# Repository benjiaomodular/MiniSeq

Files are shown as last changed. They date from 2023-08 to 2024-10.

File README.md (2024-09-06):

# MiniSeq
[][cc-by-sa]

Full docs on my website: https://benjiaomodular.com/post/miniseq/

This is my second time building a Baby-8 step CV sequencer since my [plexiglass Baby-8 build](https://benjiaomodular.com/post/2021-04-09-8-step-sequencer) from two years ago. This, time I added a gate output, a reset input, and a step length control.

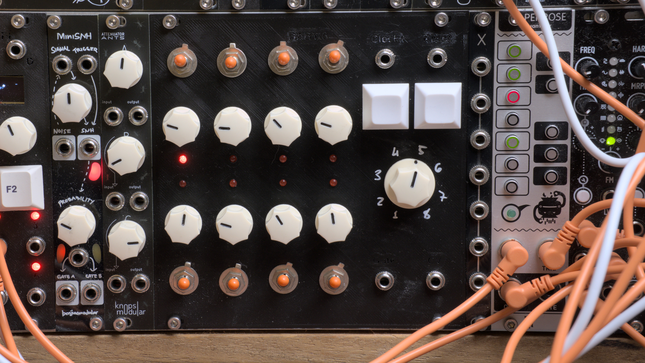
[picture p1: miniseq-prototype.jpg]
"My prototype for the MiniSeq build on a 3D printed panel"
 

## Schematics

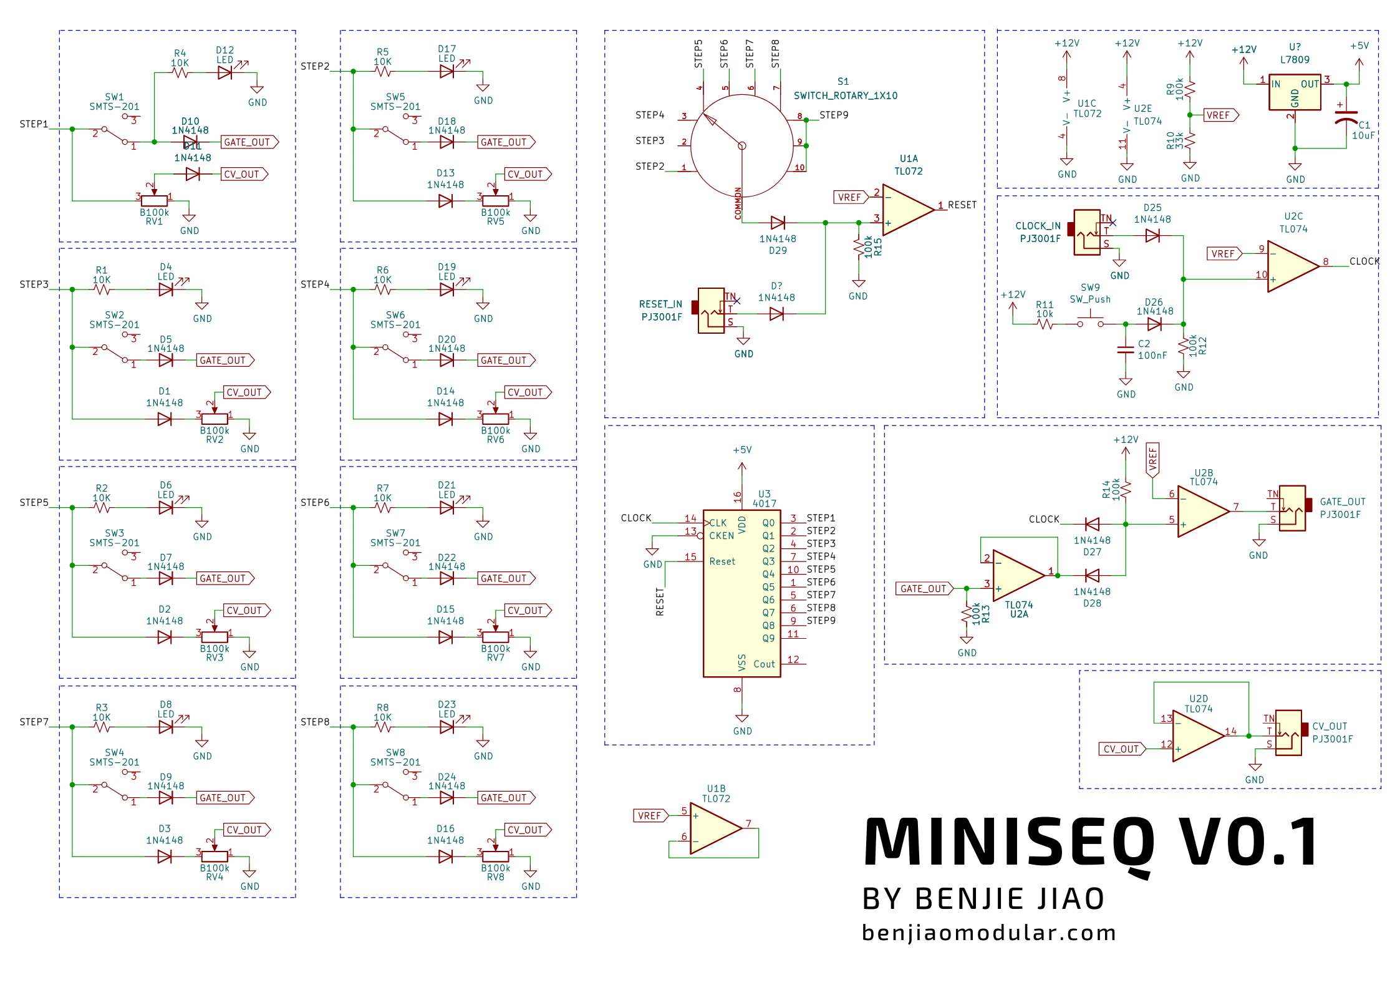
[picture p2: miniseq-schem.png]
"MiniSeq Schematics"
 

## License

This work is licensed under a
[Creative Commons Attribution-ShareAlike 4.0 International License][cc-by-sa].

[][cc-by-sa]

[cc-by-sa]: http://creativecommons.org/licenses/by-sa/4.0/
[cc-by-sa-image]: https://licensebuttons.net/l/by-sa/4.0/88x31.png
[cc-by-sa-shield]: https://img.shields.io/badge/License-CC%20BY--SA%204.0-lightgrey.svg

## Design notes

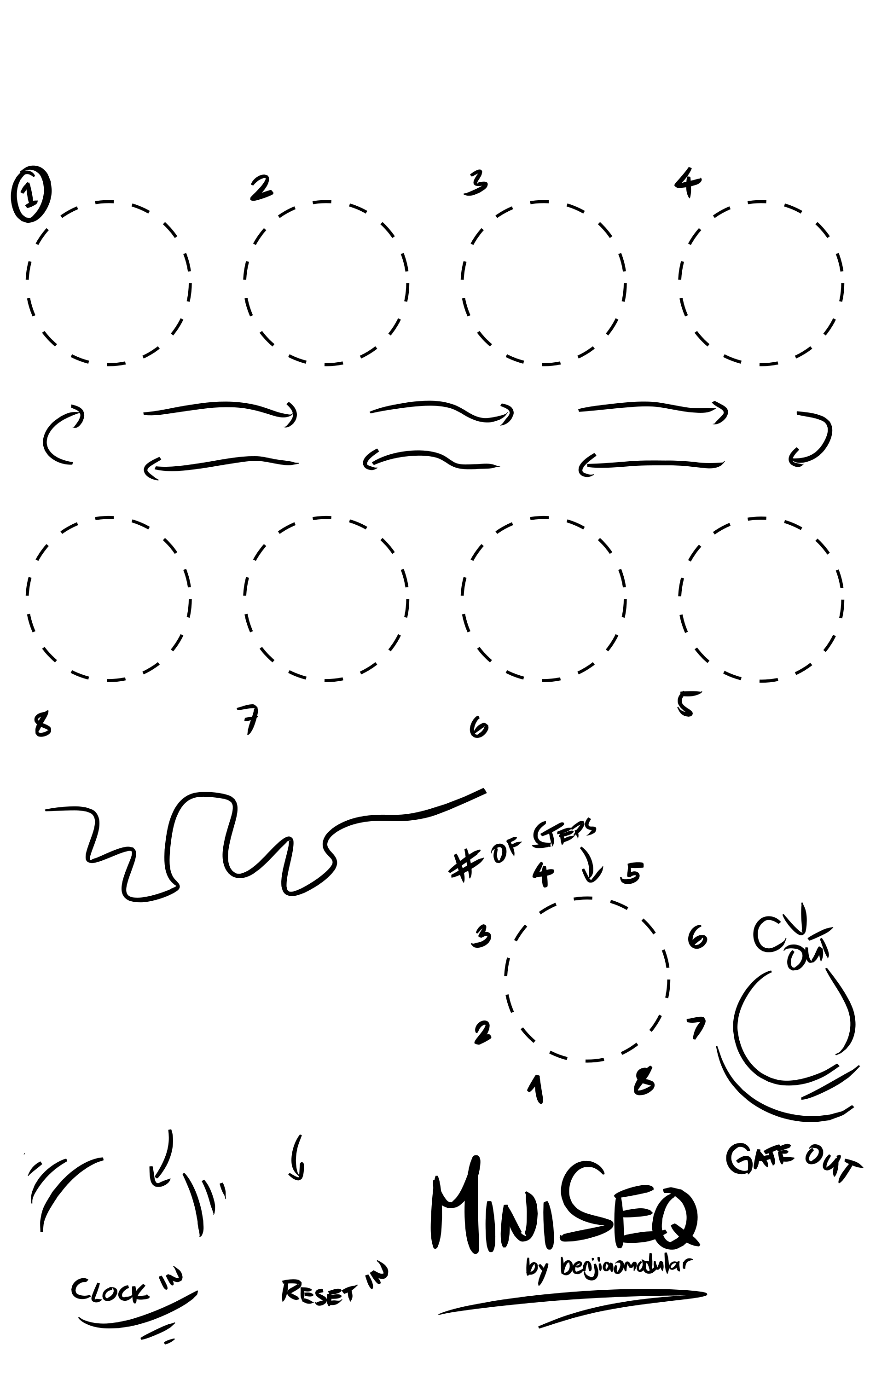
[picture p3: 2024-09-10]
hardware/panel/MiniSeq - Panel.png

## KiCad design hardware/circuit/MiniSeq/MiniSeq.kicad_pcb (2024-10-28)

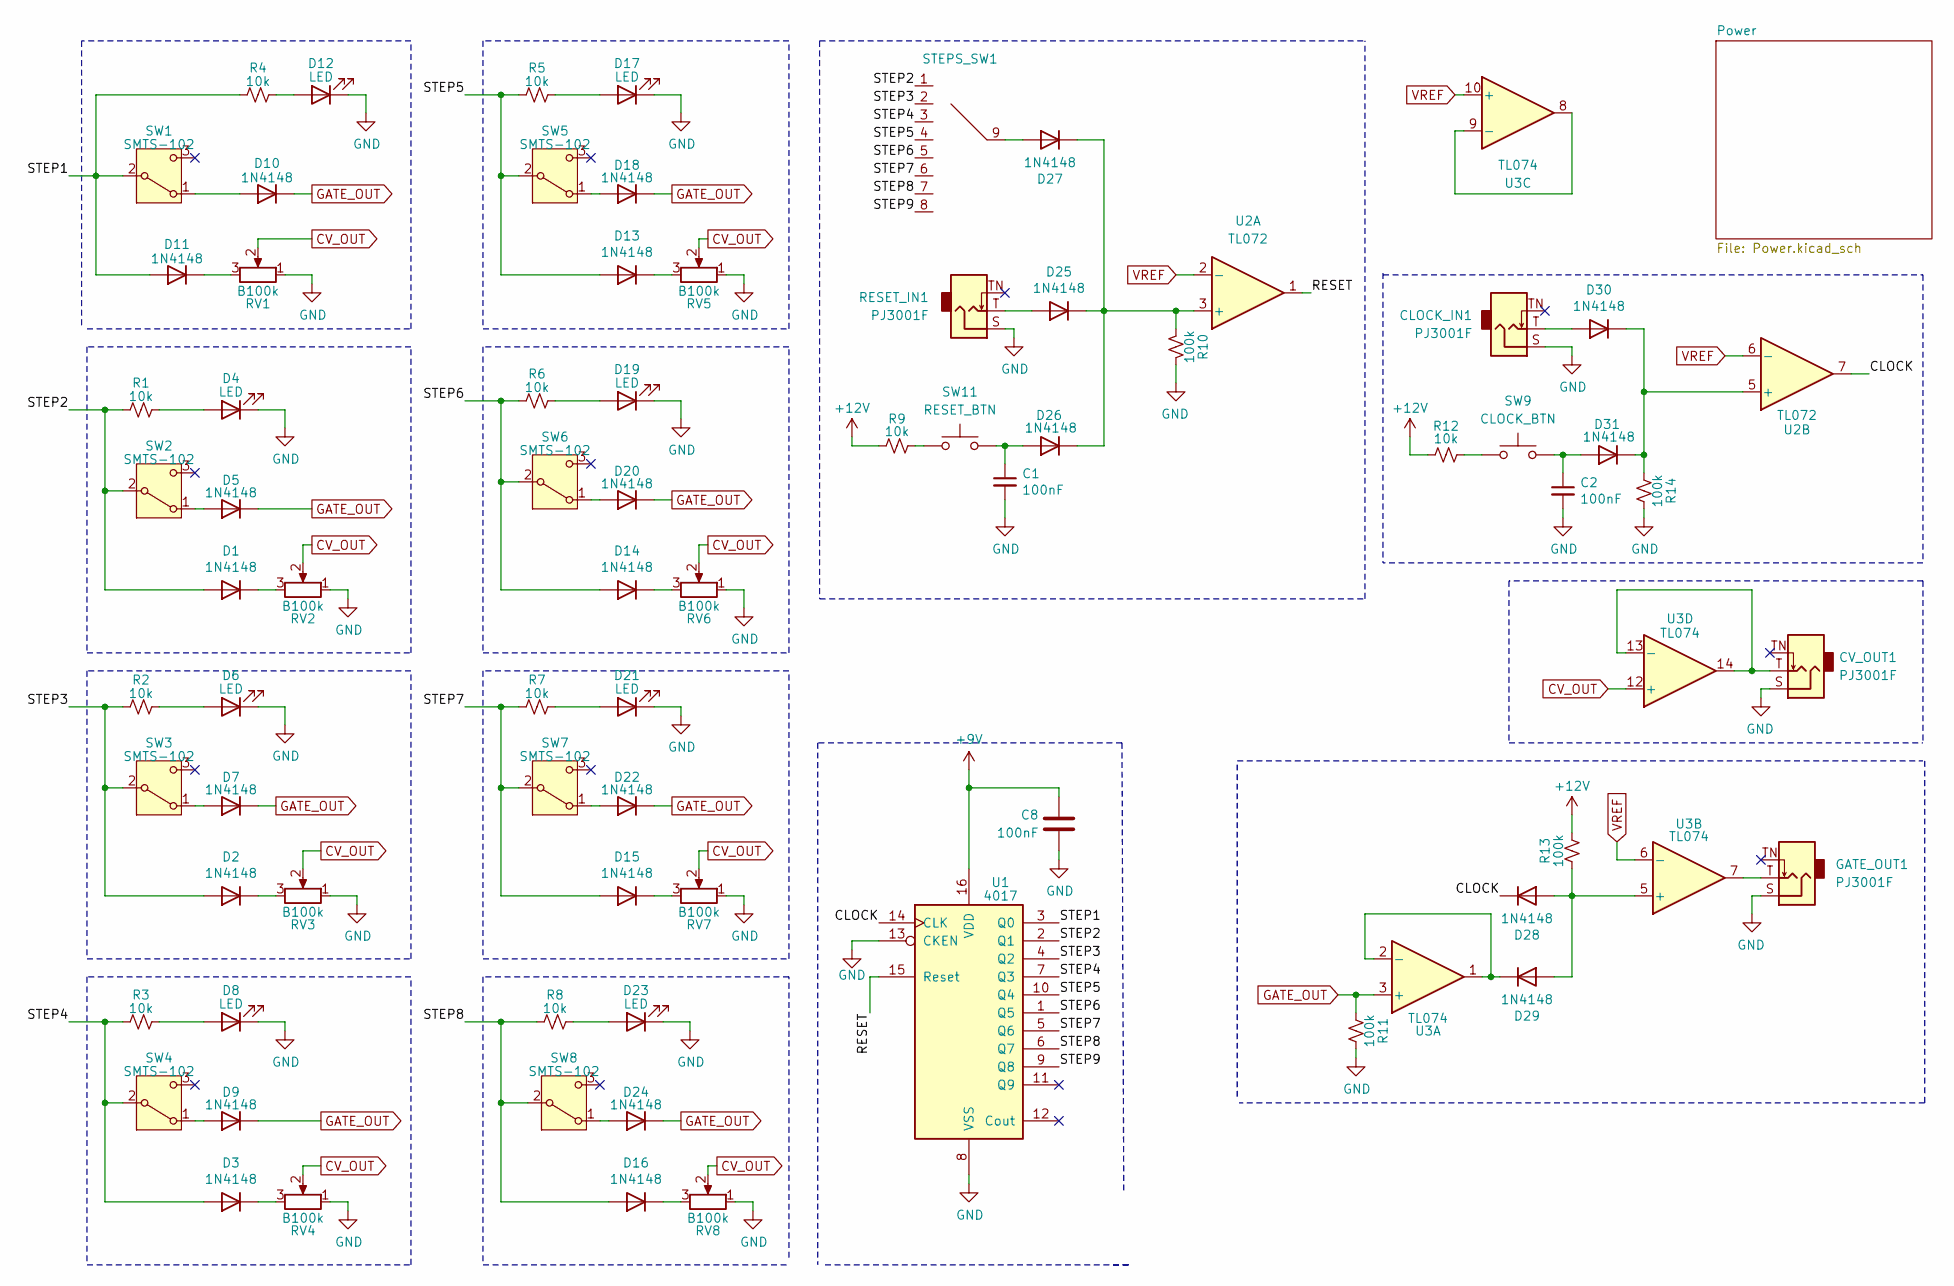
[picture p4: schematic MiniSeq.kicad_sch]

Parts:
C1, C2: 100nF; C_0805_2012Metric_Pad1.18x1.45mm_HandSolder; Manufacturers Part Numb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 CC0805KRX7R9BB104
C8: 100nF; C_0805_2012Metric_Pad1.18x1.45mm_HandSolder
CLOCK_IN1: PJ3001F; AudioJack_3.5mm; Manufacturers Part Numb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 PJ-3001F
CV_OUT1: PJ3001F; AudioJack_3.5mm; Manufacturers Part Numb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 PJ-3001F
D1, D2, D3, D5, D7, D9, D10, D11, D13, D14, D15, D16, D18, D20, D22, D24, D25, D26, D27, D28, D29, D30, D31: 1N4148; D_SOD-123; Manufacturers Part Numb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 1N4148WQ-7-F
D4, D6, D8, D12, D17, D19, D21, D23: LED; LED_D3.0mm
GATE_OUT1: PJ3001F; AudioJack_3.5mm; Manufacturers Part Numb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 PJ-3001F
R1, R2, R3, R4, R5, R6, R7, R8, R9, R12: 10k; R_0603_1608Metric_Pad0.98x0.95mm_HandSolder; Manufacturers Part Numb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 AC0603FR-0710KL
R10, R11, R13, R14: 100k; R_0603_1608Metric_Pad0.98x0.95mm_HandSolder; Manufacturers Part Numb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 RC0603FR-07100KL
RESET_IN1: PJ3001F; AudioJack_3.5mm; Manufacturers Part Numb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 PJ-3001F
RV1, RV2, RV3, RV4, RV5, RV6, RV7, RV8: B100k; Potentiometer_RV09; Manufacturers Part Numb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 RD901F-40-15R1-B100K
STEPS_SW1: RotarySwitch_SR16_POLE1_WAY8
SW1, SW2, SW3, SW4, SW5, SW6, SW7, SW8: SMTS-102; ToggleSwitch_SMTS-102; Manufacturers Part Numb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 SMTS-201
SW9: CLOCK_BTN; SW_Cherry_MX_1.00u_PCB
SW11: RESET_BTN; SW_Cherry_MX_1.00u_PCB
U1: 4017; SOIC-16W_5.3x10.2mm_P1.27mm; Manufacturers Part Numb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 CD40174BM96
U2: TL072; SOIC-8_3.9x4.9mm_P1.27mm; Manufacturers Part Numb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 TL072CDT
U3: TL074; SOIC-14_3.9x8.7mm_P1.27mm; Manufacturers Part Numb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 TL074ACDT

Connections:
+9V: C8.1, U1.16 (VDD); also elsewhere on the board
+12V: R9.2, R12.2, R13.1; also elsewhere on the board
/CLOCK: D28.1 (K), U1.14 (CLK), U2.7
/RESET: U1.15 (Reset), U2.1
/STEP1: D11.2 (A), R4.2, SW1.2 (B), U1.3 (Q0)
/STEP2: D1.2 (A), R1.2, STEPS_SW1.1, SW2.2 (B), U1.2 (Q1)
/STEP3: D2.2 (A), R2.2, STEPS_SW1.2, SW3.2 (B), U1.4 (Q2)
/STEP4: D3.2 (A), R3.2, STEPS_SW1.3, SW4.2 (B), U1.7 (Q3)
/STEP5: D13.2 (A), R5.2, STEPS_SW1.4, SW5.2 (B), U1.10 (Q4)
/STEP6: D14.2 (A), R6.2, STEPS_SW1.5, SW6.2 (B), U1.1 (Q5)
/STEP7: D15.2 (A), R7.2, STEPS_SW1.6, SW7.2 (B), U1.5 (Q6)
/STEP8: D16.2 (A), R8.2, STEPS_SW1.7, SW8.2 (B), U1.6 (Q7)
/STEP9: STEPS_SW1.8, U1.9 (Q8)
CV_OUT: RV1.2, RV2.2, RV3.2, RV4.2, RV5.2, RV6.2, RV7.2, RV8.2, U3.12 (+)
GATE_OUT: D5.1 (K), D7.1 (K), D9.1 (K), D10.1 (K), D18.1 (K), D20.1 (K), D22.1 (K), D24.1 (K), R11.2, U3.3 (+)
GND: C1.2, C2.2, C8.2, CLOCK_IN1.S, CV_OUT1.S, D4.1 (K), D6.1 (K), D8.1 (K), D12.1 (K), D17.1 (K), D19.1 (K), D21.1 (K), D23.1 (K), GATE_OUT1.S, R10.2, R11.1, R14.1, RESET_IN1.S, RV1.1, RV2.1, RV3.1, RV4.1, RV5.1, RV6.1, RV7.1, RV8.1, U1.8 (VSS), U1.13 (CKEN); also elsewhere on the board
unnamed: D1.1 (K), RV2.3
unnamed: D2.1 (K), RV3.3
unnamed: D3.1 (K), RV4.3
unnamed: D4.2 (A), R1.1
unnamed: D5.2 (A), SW2.1 (A)
unnamed: D6.2 (A), R2.1
unnamed: D7.2 (A), SW3.1 (A)
unnamed: D8.2 (A), R3.1
unnamed: D9.2 (A), SW4.1 (A)
unnamed: D10.2 (A), SW1.1 (A)
unnamed: D11.1 (K), RV1.3
unnamed: D12.2 (A), R4.1
unnamed: D13.1 (K), RV5.3
unnamed: D14.1 (K), RV6.3
unnamed: D15.1 (K), RV7.3
unnamed: D16.1 (K), RV8.3
unnamed: D17.2 (A), R5.1
unnamed: D18.2 (A), SW5.1 (A)
unnamed: D19.2 (A), R6.1
unnamed: D20.2 (A), SW6.1 (A)
unnamed: D21.2 (A), R7.1
unnamed: D22.2 (A), SW7.1 (A)
unnamed: D23.2 (A), R8.1
unnamed: D24.2 (A), SW8.1 (A)
unnamed: D25.2 (A), RESET_IN1.T
unnamed: D25.1 (K), D26.1 (K), D27.1 (K), R10.1, U2.3 (+)
unnamed: C1.1, D26.2 (A), SW11.2
unnamed: D27.2 (A), STEPS_SW1.9
unnamed: D28.2 (A), D29.2 (A), R13.2, U3.5 (+)
unnamed: D29.1 (K), U3.1, U3.2 (-)
unnamed: CLOCK_IN1.T, D30.2 (A)
unnamed: D30.1 (K), D31.1 (K), R14.2, U2.5 (+)
unnamed: C2.1, D31.2 (A), SW9.2
unnamed: GATE_OUT1.T, U3.7
unnamed: R9.1, SW11.1
unnamed: R12.1, SW9.1
unnamed: U3.8, U3.9 (-)
unnamed: CV_OUT1.T, U3.13 (-), U3.14
VREF: U2.2 (-), U2.6 (-), U3.6 (-), U3.10 (+); also elsewhere on the board

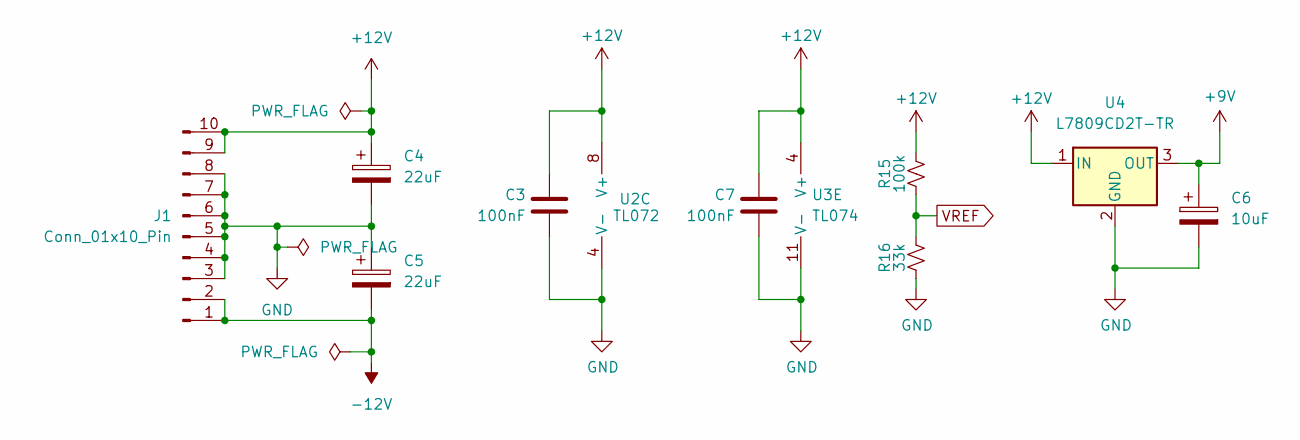
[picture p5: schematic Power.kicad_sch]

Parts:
C3, C7: 100nF; C_0805_2012Metric_Pad1.18x1.45mm_HandSolder
C4, C5: 22uF; CP_Elec_4x3.9
C6: 10uF; C_0805_2012Metric_Pad1.18x1.45mm_HandSolder
J1: Conn_01x10_Pin; IDC-Header_2x05_P2.54mm_Vertical
R15: 100k; R_0603_1608Metric_Pad0.98x0.95mm_HandSolder; Manufacturers Part Numb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 RC0603FR-07100KL
R16: 33k; R_0603_1608Metric_Pad0.98x0.95mm_HandSolder; Manufacturers Part Numb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 CR0603-FX-3302ELF
U2: TL072; SOIC-8_3.9x4.9mm_P1.27mm; Manufacturers Part Numb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 TL072CDT
U3: TL074; SOIC-14_3.9x8.7mm_P1.27mm; Manufacturers Part Numb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 TL074ACDT
U4: L7809CD2T-TR; TO-252-2; Manufacturers Part Numb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 L7809CD2T-TR

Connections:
+9V: C6.1, U4.3 (OUT); also elsewhere on the board
+12V: C3.1, C4.1, C7.1, J1.9, J1.10, R15.1, U2.8 (V+), U3.4 (V+), U4.1 (IN); also elsewhere on the board
-12V: C5.2, J1.1, J1.2
GND: C3.2, C4.2, C5.1, C6.2, C7.2, J1.3, J1.4, J1.5, J1.6, J1.7, J1.8, R16.2, U2.4 (V-), U3.11 (V-), U4.2 (GND); also elsewhere on the board
VREF: R15.2, R16.1; also elsewhere on the board

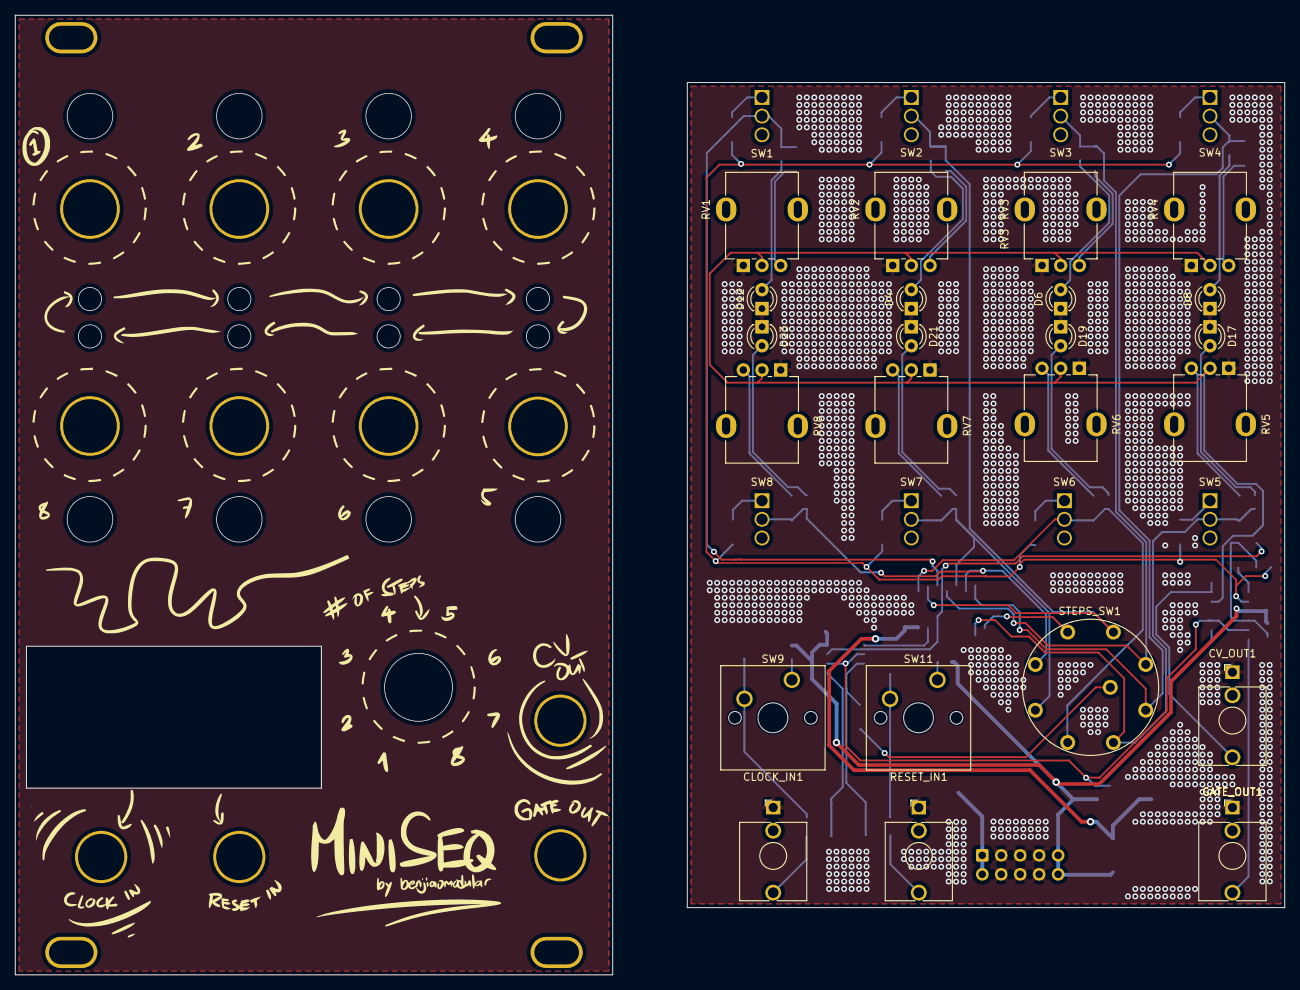
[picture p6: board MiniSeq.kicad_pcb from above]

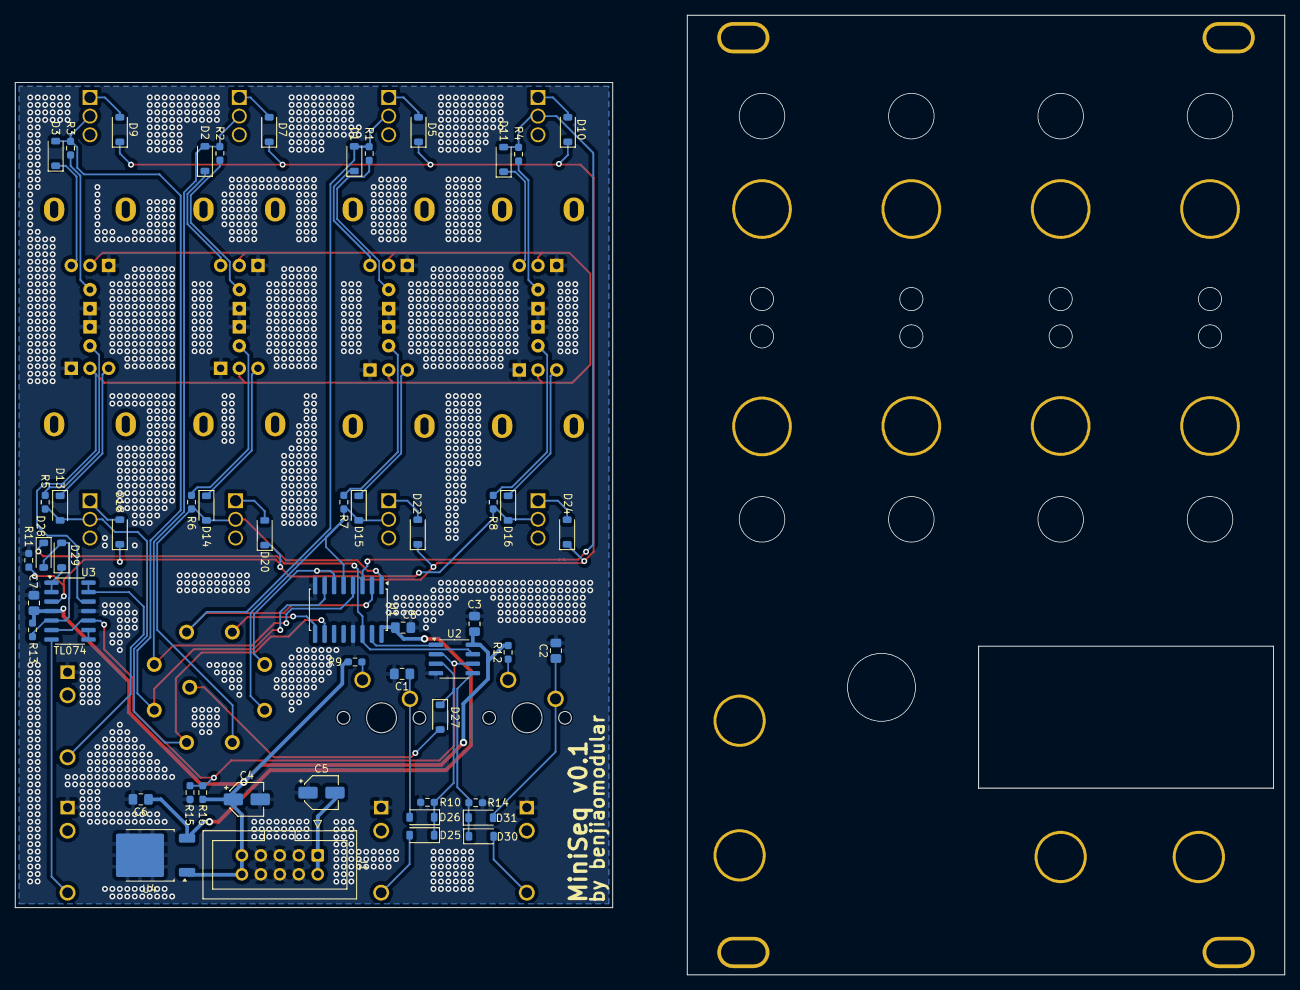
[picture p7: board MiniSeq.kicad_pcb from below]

Board: 2 copper layers, 80.0 x 110.5 mm, 83 parts (52 on the bottom side), 56 nets.

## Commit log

2023-08-19 Fixed schematic layout
    [MiniSeq.kicad_sch]
2023-08-29 Added some docs + schematics
    [MiniSeq.kicad_sch]
2024-09-06 Reorganized files
    [MiniSeq.kicad_pcb, MiniSeq.kicad_sch, Power.kicad_sch]
2024-09-10 v0.1 PCBs
    [MiniSeq - Main.kicad_pcb, MiniSeq - Panel.kicad_pcb, MiniSeq.kicad_sch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]
2024-09-11 Added copper fills to panel
    [MiniSeq - Panel-B_Cu.gbr, MiniSeq - Panel-B_Mask.gbr, MiniSeq - Panel-B_Paste.gbr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]
2024-10-28 Updated PCBs for v0.1
    [MiniSeq - Main.kicad_pcb, MiniSeq - Panel.kicad_pcb, MiniSeq.kicad_pcb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]

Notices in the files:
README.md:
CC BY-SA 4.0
